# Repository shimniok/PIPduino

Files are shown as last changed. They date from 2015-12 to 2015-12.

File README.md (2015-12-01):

PIPduino
========

A 'duino clone you can Put In a Project. Small, breadboard-friendly 'duinos are compact and work
great on a breadboard. But you need a baseboard to embed them in a project.

PIPduino already has ports for I2C, SPI, Serial/FTDI, and servo-style connectors with VCC and GND
for each analog and digital pin.  It has a beefy regulator on board, too.

Buy one now on [Tindie](https://www.tindie.com/products/bot_thoughts/pipduino/).

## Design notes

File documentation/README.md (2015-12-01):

# PIPduino User Guide

PIPduino is a 'duino is easier and cheaper to permanently Put In a Project than the standard Arduino. [For sale on Tindie](https://www.tindie.com/products/bot_thoughts/pipduino).

## Overview

 * Use standalone boards from [Sparkfun](https://www.sparkfun.com/), [Pololu](http://www.pololu.com/), [Adafruit](https://www.adafruit.com/), etc.
 * ```I2C``` port with 4 connections for interfacing all those sensors
 * ```SPI/ISP``` port can be used for AVR In-System Programming or SPI port
 * All Digital and Analog pins exposed.
 * Servo-style ```signal```, ```VCC```, ```GND``` pins on *DIGITAL* and *ANALOG* ports
 * Select from a wide variety of power supply options
 * Programming and/or serial on ```FTDI``` port
 * ATmega328P at 16MHz, Arduino Optiboot, looks like an Uno board
 * Optional 3mm indicator LEDs (leave them off to reduce power consumption)
 * And more...

## Pinout
The PIPduino breaks out dedicated digital and analog pins as well as pins for Serial, SPI, and I2C. The tables below list all the Arduino Pins, and the PIPduino *Port* they are found on, and alternate functions.

### Digital

The primary function of the pins below is Arduino digital input and output.
Pins D10-D13 are also used for SPI (See *SPI/ISP* below).

| Arduino Pin | Alternate | Port |
|:---:|---|---|
| D0 | Serial RX (FTDI TXO) | FTDI |
| D1 | Serial TX (FTDI RXI) | FTDI |
| D2 | - | DIGITAL |
| D3 | PWM | DIGITAL |
| D4 | - | DIGITAL |
| D5 | PWM | DIGITAL |
| D6 | PWM | DIGITAL |
| D7 | - | DIGITAL |
| D8 | - | DIGITAL |
| D9 | PWM | DIGITAL |
| D10 | PWM | DIGITAL |
| D11 | PWM | SPI/ISP |
| D12 | - | SPI/ISP |
| D13 | LED | SPI/ISP |

### Analog

Arduino analog pins can also be used for digital input/output. Pins A4-A5 are
used for I2C (See *I2C* below). Pins A6-A7 are analog input, only.

| Arduino Pin | Alternate | Port |
|:---:|---|---|
| A0 | Digital | ANALOG |
| A1 | Digital | ANALOG |
| A2 | Digital | ANALOG |
| A3 | Digital | ANALOG |
| A4 | Digital, SDA | I2C |
| A5 | Digital, SCL | I2C |
| A6 | - | ANALOG |
| A7 | - | ANALOG |

### SPI/ISP
The SPI port doubles as the In-System Programming port (AVRISP). Use the SS
solder jumper under the board to select SPI:D10 to use the SPI port with D10
as the active-low Slave Select pin.

| Arduino Pin | Function | Port |
|:---:|---|---|
| D10 | SS | SPI/ISP |
| D11 | MOSI | SPI/ISP |
| D12 | MISO | SPI/ISP |
| D13 | SCK | SPI/ISP |

NOTE: there is a silkscreen error on R0.2: the SS solder jumper silkscreen
identifies the wrong digital pin for SPI operation. In fact, D10 is used for
Slave Select.

### I2C
The A4 and A5 pins are dedicated to I2C SDA and SCL use, respectively, since so
many sensors speak I2C. SMT pull-up resistors are installed on the board for
these pins. The board has connections for four I2C devices but you can also
daisy chain I2C devices, too.

| Arduino Pin | Function | Port |
|:---:|---|---|
| A4 | SDA | I2C |
| A5 | SCL | I2C |

### Serial / FTDI
The D0 and D1 pins are broken out to the FTDI/Serial port for TX (FTDI RXI) and RX (FTDI TXO) pins, respectively. The FTDI pins can be used for Arduino program downloading, or can be used for serial I/O. Because there's no pull-up they can also be used for GPIO pins D0 and D1.

| Arduino Pin | Function | FTDI | Port |
|:---:|---|:---:|---|
| D0 | Serial TX | RXI | FTDI |
| D1 | Serial RX | TXO | FTDI |

## Programming
### Arduino
PIPduino is Arduino compatible, so use the good ol' Arduino IDE.

### FTDI
Program with a standard FTDI cable or Sparkfun FTDI basic breakout or equivalent. Within the Arduino IDE, select the appropriate serial device, and choose "Arduino Uno" as the board.

### ISP
You can also program with ISP. On the bottom of the board, use the SS solder jumper to select ISP:RES for ISP programming.

## Power
Several options are available for powering your PIPduino and sensors/devices.

### Powering the Board
* Use the onboard regulator. Connect the VIN/GND port to a supply of anywhere from Vcc+0.23V to 16V.
* Bypass the regulator and supply 3.3V or 5V directly to any VCC/GND pin pair.
* FTDI can supply voltage through the VCC pin if the board is not powered. A diode allows you to plug in FTDI whether the board is already powered or not. It drops 0.2-0.5V depending on current draw.

CAUTION: in any case above, your FTDI adapter's output voltage must be LESS THAN the voltage on the VCC pins of the POWER, ANALOG, DIGITAL, and I2C ports.

### Powering Devices
A VCC and GND pin are provided for every port with a servo-style pinout (Signal, VCC, GND), plus there is a power distribution port, POWER, with 4 additional VCC/GND pairs. In most cases, the easiest option is to simply build a 0.1" pitch header/cable (or use a pre-built servo connector) to connect your device.

If your device requires a 3.3V supply, you can either use a separate regulator board to power 3.3V devices or use a 3.3V PIPduino.

### Onboard Regulator
The onboard regulator features reverse bias protection and thermal shutdown protection. Because of the DPAK package for the regulator IC and due to robust thermal design of the board, it has been tested to supply a full 500mA continuous without going into thermal shutdown.

In fact, I torture-tested the board, powering it with a 3S LiPo (~12V), dumping out over 520mA (above the rated spec for the regulator) for a good five minutes. The hottest spot I measured was a stable 140°C on the tab. Ambient temperature was 22°C. The regulator never went into thermal shutdown. When tested at approximately 250mA, the hottest temperature I found after several minutes was a stable 93°C.

Note that a lower input voltage won't make so much heat. And drawing less current means less heat. A higher ambient temperature will reduce heat dissipation, so keep that in mind.

CAUTION: when supplying maximum current, the board gets REALLY HOT!!

## Mounting

* Mounting holes for M3 (#4) size screws on a 40mm square
* Board size is 46mm (13/16") square

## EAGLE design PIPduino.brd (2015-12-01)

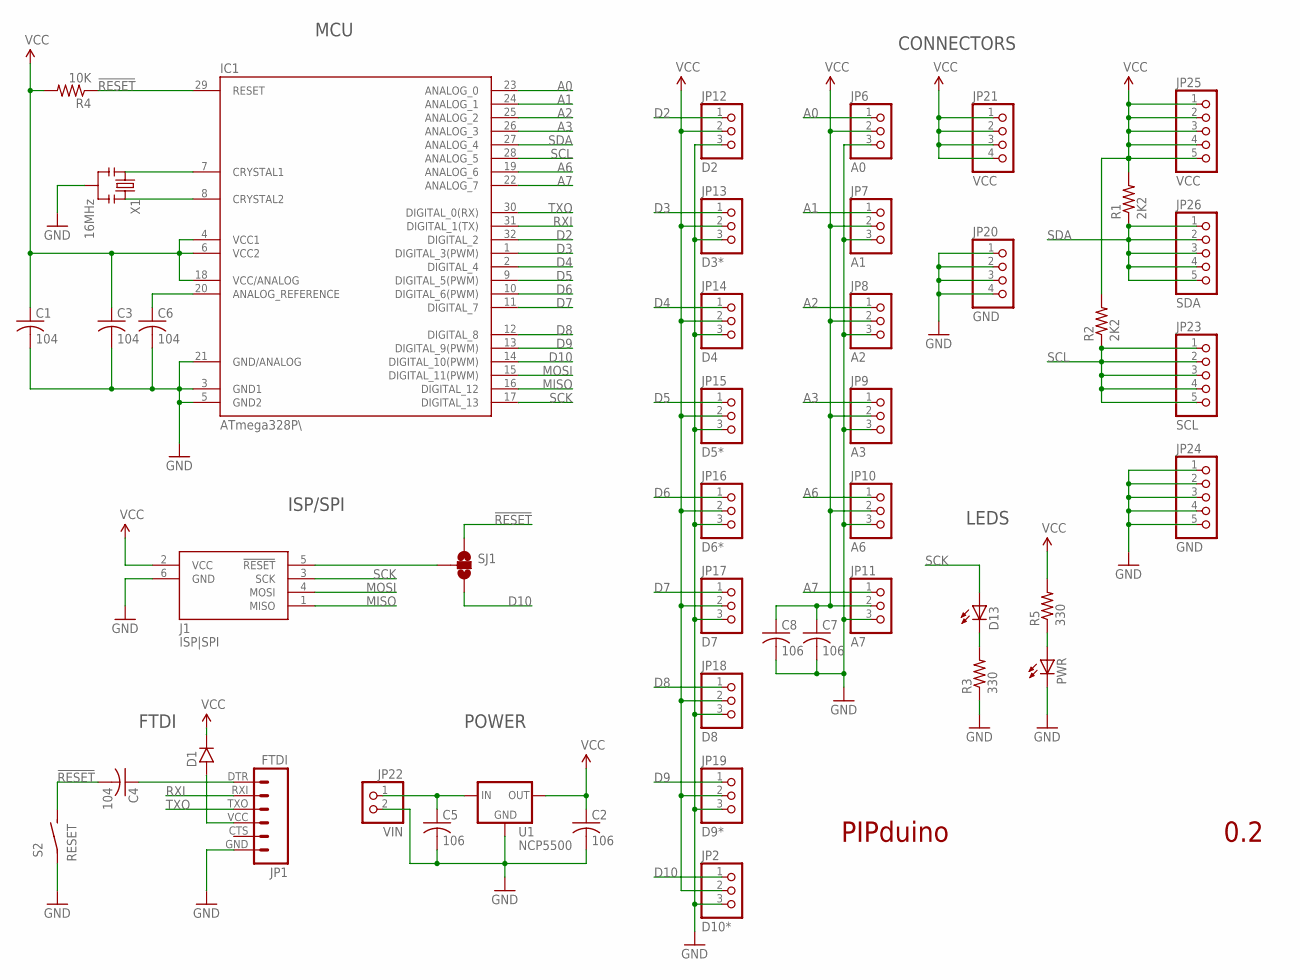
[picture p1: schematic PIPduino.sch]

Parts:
C1, C3, C4, C6: 104; C0603
C2, C5, C7, C8: 106; C1206
D1: DIODE_SOD123FL; SOD123FL
D13: LED3MM
IC1: ATmega328P\; TQFP32-08
J1: ISP|SPI; CON6P2R
JP1: FTDI; FTDI_BASIC
JP2: D10*; 1X03-S
JP6: A0; 1X03-S
JP7: A1; 1X03-S
JP8: A2; 1X03-S
JP9: A3; 1X03-S
JP10: A6; 1X03-S
JP11: A7; 1X03-S
JP12: D2; 1X03-S
JP13: D3*; 1X03-S
JP14: D4; 1X03-S
JP15: D5*; 1X03-S
JP16: D6*; 1X03-S
JP17: D7; 1X03-S
JP18: D8; 1X03-S
JP19: D9*; 1X03-S
JP20: GND; 1X04-S
JP21: VCC; 1X04-S
JP22: VIN; 1X02-S
JP23: SCL; 1X05-S
JP24: GND; 1X05-S
JP25: VCC; 1X05-S
JP26: SDA; 1X05-S
PWR: LED3MM
R1, R2: 2K2; R0603
R3, R5: 330; R0603
R4: 10K; R0603
S2: RESET; 3X4X2TACT
SJ1: SOLDERJUMPER_2WAYS; SJ_3
U1: NCP5500; DPAK
X1: 16MHz; CSTCE_V_C

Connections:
!RESET: C4.2, IC1.29 (RESET), R4.1, S2.P$2 (S), SJ1.1
A0: IC1.23 (ANALOG_0), JP6.1
A1: IC1.24 (ANALOG_1), JP7.1
A2: IC1.25 (ANALOG_2), JP8.1
A3: IC1.26 (ANALOG_3), JP9.1
A6: IC1.19 (ANALOG_6), JP10.1
A7: IC1.22 (ANALOG_7), JP11.1
D2: IC1.32 (DIGITAL_2), JP12.1
D3: IC1.1 (DIGITAL_3(PWM)), JP13.1
D4: IC1.2 (DIGITAL_4), JP14.1
D5: IC1.9 (DIGITAL_5(PWM)), JP15.1
D6: IC1.10 (DIGITAL_6(PWM)), JP16.1
D7: IC1.11 (DIGITAL_7), JP17.1
D8: IC1.12 (DIGITAL_8), JP18.1
D9: IC1.13 (DIGITAL_9(PWM)), JP19.1
D10: IC1.14 (DIGITAL_10(PWM)), JP2.1, SJ1.3
GND: C1.2, C2.2, C3.2, C5.2, C6.2, C7.2, C8.2, IC1.3 (GND1), IC1.5 (GND2), IC1.21 (GND/ANALOG), J1.6 (GND), JP1.GND (6), JP2.3, JP6.3, JP7.3, JP8.3, JP9.3, JP10.3, JP11.3, JP12.3, JP13.3, JP14.3, JP15.3, JP16.3, JP17.3, JP18.3, JP19.3, JP20.1, JP20.2, JP20.3, JP20.4, JP22.2, JP24.1, JP24.2, JP24.3, JP24.4, JP24.5, PWR.K (C), R3.1, S2.P$1, U1.4 (GND), X1.GND
MISO: IC1.16 (DIGITAL_12), J1.1 (MISO)
MOSI: IC1.15 (DIGITAL_11(PWM)), J1.4 (MOSI)
unnamed: D13.K (C), R3.2
unnamed: C5.1, JP22.1, U1.1 (VIN)
unnamed: J1.5 (!RESET), SJ1.2
unnamed: PWR.A, R5.1
unnamed: D1.A, JP1.VCC (4)
unnamed: C6.1, IC1.20 (ANALOG_REFERENCE)
unnamed: IC1.7 (CRYSTAL1), X1.X1
unnamed: IC1.8 (CRYSTAL2), X1.X2
unnamed: C4.1, JP1.DTR (1)
RXI: IC1.31 (DIGITAL_1(TX)), JP1.RXI (2)
SCK: D13.A, IC1.17 (DIGITAL_13), J1.3 (SCK)
SCL: IC1.28 (ANALOG_5), JP23.1, JP23.2, JP23.3, JP23.4, JP23.5, R2.1
SDA: IC1.27 (ANALOG_4), JP26.1, JP26.2, JP26.3, JP26.4, JP26.5, R1.1
TXO: IC1.30 (DIGITAL_0(RX)), JP1.TXO (3)
VCC: C1.1, C2.1, C3.1, C7.1, C8.1, D1.C, IC1.4 (VCC1), IC1.6 (VCC2), IC1.18 (VCC/ANALOG), J1.2 (VCC), JP2.2, JP6.2, JP7.2, JP8.2, JP9.2, JP10.2, JP11.2, JP12.2, JP13.2, JP14.2, JP15.2, JP16.2, JP17.2, JP18.2, JP19.2, JP21.1, JP21.2, JP21.3, JP21.4, JP25.1, JP25.2, JP25.3, JP25.4, JP25.5, R1.2, R2.2, R4.2, R5.2, U1.3 (VOUT)

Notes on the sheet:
FTDI
POWER
ISP/SPI
MCU
CONNECTORS
LEDS
PIPduino
0.2

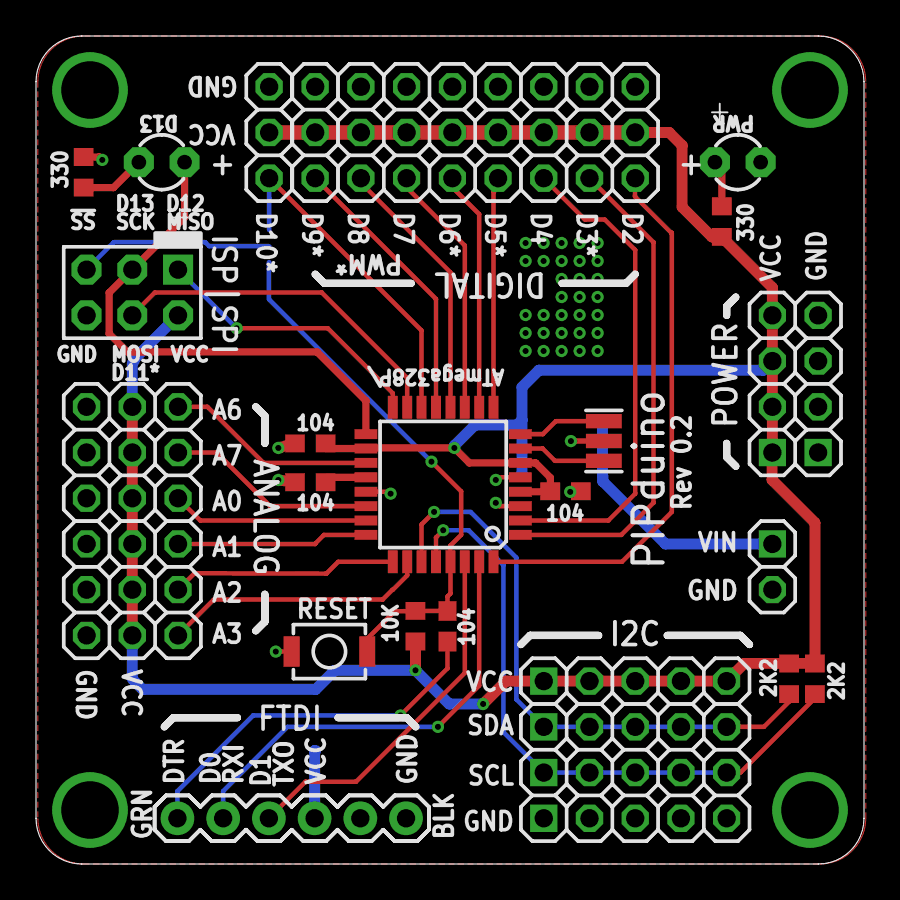
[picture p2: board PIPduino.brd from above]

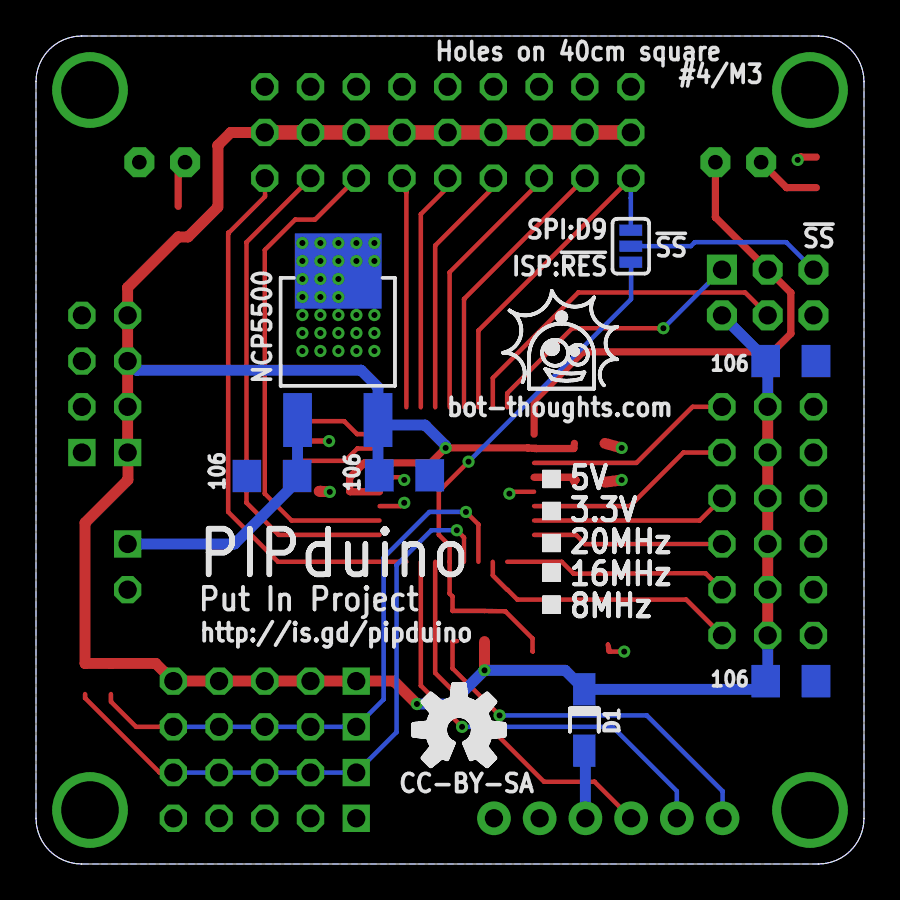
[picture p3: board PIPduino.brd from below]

Board: 2 copper layers, 46.0 x 46.0 mm, 45 parts (7 on the bottom side), 34 nets.

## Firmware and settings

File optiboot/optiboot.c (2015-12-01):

/**********************************************************/
/* Optiboot bootloader for Arduino                        */
/*                                                        */
/* http://optiboot.googlecode.com                         */
/*                                                        */
/* Arduino-maintained version : See README.TXT            */
/* http://code.google.com/p/arduino/                      */
/*                                                        */
/* Heavily optimised bootloader that is faster and        */
/* smaller than the Arduino standard bootloader           */
/*                                                        */
/* Enhancements:                                          */
/*   Fits in 512 bytes, saving 1.5K of code space         */
/*   Background page erasing speeds up programming        */
/*   Higher baud rate speeds up programming               */
/*   Written almost entirely in C                         */
/*   Customisable timeout with accurate timeconstant      */
/*   Optional virtual UART. No hardware UART required.    */
/*   Optional virtual boot partition for devices without. */
/*                                                        */
/* What you lose:                                         */
/*   Implements a skeleton STK500 protocol which is       */
/*     missing several features including EEPROM          */
/*     programming and non-page-aligned writes            */
/*   High baud rate breaks compatibility with standard    */
/*     Arduino flash settings                             */
/*                                                        */
/* Fully supported:                                       */
/*   ATmega168 based devices  (Diecimila etc)             */
/*   ATmega328P based devices (Duemilanove etc)           */
/*                                                        */
/* Alpha test                                             */
/*   ATmega1280 based devices (Arduino Mega)              */
/*                                                        */
/* Work in progress:                                      */
/*   ATmega644P based devices (Sanguino)                  */
/*   ATtiny84 based devices (Luminet)                     */
/*                                                        */
/* Does not support:                                      */
/*   USB based devices (eg. Teensy)                       */
/*                                                        */
/* Assumptions:                                           */
/*   The code makes several assumptions that reduce the   */
/*   code size. They are all true after a hardware reset, */
/*   but may not be true if the bootloader is called by   */
/*   other means or on other hardware.                    */
/*     No interrupts can occur                            */
/*     UART and Timer 1 are set to their reset state      */
/*     SP points to RAMEND                                */
/*                                                        */
/* Code builds on code, libraries and optimisations from: */
/*   stk500boot.c          by Jason P. Kyle               */
/*   Arduino bootloader    http://arduino.cc              */
/*   Spiff's 1K bootloader http://spiffie.org/know/arduino_1k_bootloader/bootloader.shtml */
/*   avr-libc project      http://nongnu.org/avr-libc     */
/*   Adaboot               http://www.ladyada.net/library/arduino/bootloader.html */
/*   AVR305                Atmel Application Note         */
/*                                                        */
/* This program is free software; you can redistribute it */
/* and/or modify it under the terms of the GNU General    */
/* Public License as published by the Free Software       */
/* Foundation; either version 2 of the License, or        */
/* (at your option) any later version.                    */
/*                                                        */
/* This program is distributed in the hope that it will   */
/* be useful, but WITHOUT ANY WARRANTY; without even the  */
/* implied warranty of MERCHANTABILITY or FITNESS FOR A   */
/* PARTICULAR PURPOSE.  See the GNU General Public        */
/* License for more details.                              */
/*                                                        */
/* You should have received a copy of the GNU General     */
/* Public License along with this program; if not, write  */
/* to the Free Software Foundation, Inc.,                 */
/* 59 Temple Place, Suite 330, Boston, MA  02111-1307 USA */
/*                                                        */
/* Licence can be viewed at                               */
/* http://www.fsf.org/licenses/gpl.txt                    */
/*                                                        */
/**********************************************************/


/**********************************************************/
/*                                                        */
/* Optional defines:                                      */
/*                                                        */
/**********************************************************/
/*                                                        */
/* BIG_BOOT:                                              */
/* Build a 1k bootloader, not 512 bytes. This turns on    */
/* extra functionality.                                   */
/*                                                        */
/* BAUD_RATE:                                             */
/* Set bootloader baud rate.                              */
/*                                                        */
/* LUDICROUS_SPEED:                                       */
/* 230400 baud :-)                                        */
/*                                                        */
/* SOFT_UART:                                             */
/* Use AVR305 soft-UART instead of hardware UART.         */
/*                                                        */
/* LED_START_FLASHES:                                     */
/* Number of LED flashes on bootup.                       */
/*                                                        */
/* LED_DATA_FLASH:                                        */
/* Flash LED when transferring data. For boards without   */
/* TX or RX LEDs, or for people who like blinky lights.   */
/*                                                        */
/* SUPPORT_EEPROM:                                        */
/* Support reading and writing from EEPROM. This is not   */
/* used by Arduino, so off by default.                    */
/*                                                        */
/* TIMEOUT_MS:                                            */
/* Bootloader timeout period, in milliseconds.            */
/* 500,1000,2000,4000,8000 supported.                     */
/*                                                        */
/**********************************************************/


/**********************************************************/
/* Version Numbers!                                       */
/*                                                        */
/* Arduino Optiboot now includes this Version number in   */
/* the source and object code.                            */
/*                                                        */
/* Version 3 was released as zip from the optiboot        */
/*  repository and was distributed with Arduino 0022.     */
/* Version 4 starts with the arduino repository commit    */
/*  that brought the arduino repository up-to-date with   */
/* the optiboot source tree changes since v3.             */
/*                                                        */
/**********************************************************/

/**********************************************************/
/* Edit History:					  */
/*							  */
/* 4.4 WestfW: add initialization of address to keep      */
/*             the compiler happy.  Change SC'ed targets. */
/*             Return the SW version via READ PARAM       */
/* 4.3 WestfW: catch framing errors in getch(), so that   */
/*             AVRISP works without HW kludges.           */
/*  http://code.google.com/p/arduino/issues/detail?id=368n*/
/* 4.2 WestfW: reduce code size, fix timeouts, change     */
/*             verifySpace to use WDT instead of appstart */
/* 4.1 WestfW: put version number in binary.		  */
/**********************************************************/

#define OPTIBOOT_MAJVER 4
#define OPTIBOOT_MINVER 4

#define MAKESTR(a) #a
#define MAKEVER(a, b) MAKESTR(a*256+b)

asm("  .section .version\n"
    "optiboot_version:  .word " MAKEVER(OPTIBOOT_MAJVER, OPTIBOOT_MINVER) "\n"
    "  .section .text\n");


#include <inttypes.h>
#include <avr/io.h>
#include <avr/pgmspace.h>

// <avr/boot.h> uses sts instructions, but this version uses out instructions
// This saves cycles and program memory.
#include "boot.h"


// We don't use <avr/wdt.h> as those routines have interrupt overhead we don't need.

#include "pin_defs.h"
#include "stk500.h"

#ifndef LED_START_FLASHES
#define LED_START_FLASHES 0
#endif

#ifdef LUDICROUS_SPEED
#define BAUD_RATE 230400L
#endif

/* set the UART baud rate defaults */
#ifndef BAUD_RATE
#if F_CPU >= 8000000L
#define BAUD_RATE   115200L // Highest rate Avrdude win32 will support
#elsif F_CPU >= 1000000L
#define BAUD_RATE   9600L   // 19200 also supported, but with significant error
#elsif F_CPU >= 128000L
#define BAUD_RATE   4800L   // Good for 128kHz internal RC
#else
#define BAUD_RATE 1200L     // Good even at 32768Hz
#endif
#endif

/* Switch in soft UART for hard baud rates */
#if (F_CPU/BAUD_RATE) > 280 // > 57600 for 16MHz
#ifndef SOFT_UART
#define SOFT_UART
#endif
#endif

/* Watchdog settings */
#define WATCHDOG_OFF    (0)
#define WATCHDOG_16MS   (_BV(WDE))
#define WATCHDOG_32MS   (_BV(WDP0) | _BV(WDE))
#define WATCHDOG_64MS   (_BV(WDP1) | _BV(WDE))
#define WATCHDOG_125MS  (_BV(WDP1) | _BV(WDP0) | _BV(WDE))
#define WATCHDOG_250MS  (_BV(WDP2) | _BV(WDE))
#define WATCHDOG_500MS  (_BV(WDP2) | _BV(WDP0) | _BV(WDE))
#define WATCHDOG_1S     (_BV(WDP2) | _BV(WDP1) | _BV(WDE))
#define WATCHDOG_2S     (_BV(WDP2) | _BV(WDP1) | _BV(WDP0) | _BV(WDE))
#ifndef __AVR_ATmega8__
#define WATCHDOG_4S     (_BV(WDP3) | _BV(WDE))
#define WATCHDOG_8S     (_BV(WDP3) | _BV(WDP0) | _BV(WDE))
#endif

/* Function Prototypes */
/* The main function is in init9, which removes the interrupt vector table */
/* we don't need. It is also 'naked', which means the compiler does not    */
/* generate any entry or exit code itself. */
int main(void) __attribute__ ((naked)) __attribute__ ((section (".init9")));
void putch(char);
uint8_t getch(void);
static inline void getNch(uint8_t); /* "static inline" is a compiler hint to reduce code size */
void verifySpace();
static inline void flash_led(uint8_t);
uint8_t getLen();
static inline void watchdogReset();
void watchdogConfig(uint8_t x);
#ifdef SOFT_UART
void uartDelay() __attribute__ ((naked));
#endif
void appStart() __attribute__ ((naked));

#if defined(__AVR_ATmega168__)
#define RAMSTART (0x100)
#define NRWWSTART (0x3800)
#elif defined(__AVR_ATmega328P__)
#define RAMSTART (0x100)
#define NRWWSTART (0x7000)
#elif defined (__AVR_ATmega644P__)
#define RAMSTART (0x100)
#define NRWWSTART (0xE000)
#elif defined(__AVR_ATtiny84__)
#define RAMSTART (0x100)
#define NRWWSTART (0x0000)
#elif defined(__AVR_ATmega1280__)
#define RAMSTART (0x200)
#define NRWWSTART (0xE000)
#elif defined(__AVR_ATmega8__) || defined(__AVR_ATmega88__)
#define RAMSTART (0x100)
#define NRWWSTART (0x1800)
#endif

/* C zero initialises all global variables. However, that requires */
/* These definitions are NOT zero initialised, but that doesn't matter */
/* This allows us to drop the zero init code, saving us memory */
#define buff    ((uint8_t*)(RAMSTART))
#ifdef VIRTUAL_BOOT_PARTITION
#define rstVect (*(uint16_t*)(RAMSTART+SPM_PAGESIZE*2+4))
#define wdtVect (*(uint16_t*)(RAMSTART+SPM_PAGESIZE*2+6))
#endif

/* main program starts here */
int main(void) {
  uint8_t ch;

  /*
   * Making these local and in registers prevents the need for initializing
   * them, and also saves space because code no longer stores to memory.
   * (initializing address keeps the compiler happy, but isn't really
   *  necessary, and uses 4 bytes of flash.)
   */
  register uint16_t address = 0;
  register uint8_t  length;

  // After the zero init loop, this is the first code to run.
  //
  // This code makes the following assumptions:
  //  No interrupts will execute
  //  SP points to RAMEND
  //  r1 contains zero
  //
  // If not, uncomment the following instructions:
  // cli();
  asm volatile ("clr __zero_reg__");
#ifdef __AVR_ATmega8__
  SP=RAMEND;  // This is done by hardware reset
#endif

  // Adaboot no-wait mod
  ch = MCUSR;
  MCUSR = 0;
  if (!(ch & _BV(EXTRF))) appStart();

#if LED_START_FLASHES > 0
  // Set up Timer 1 for timeout counter
  TCCR1B = _BV(CS12) | _BV(CS10); // div 1024
#endif
#ifndef SOFT_UART
#ifdef __AVR_ATmega8__
  UCSRA = _BV(U2X); //Double speed mode USART
  UCSRB = _BV(RXEN) | _BV(TXEN);  // enable Rx & Tx
  UCSRC = _BV(URSEL) | _BV(UCSZ1) | _BV(UCSZ0);  // config USART; 8N1
  UBRRL = (uint8_t)( (F_CPU + BAUD_RATE * 4L) / (BAUD_RATE * 8L) - 1 );
#else
  UCSR0A = _BV(U2X0); //Double speed mode USART0
  UCSR0B = _BV(RXEN0) | _BV(TXEN0);
  UCSR0C = _BV(UCSZ00) | _BV(UCSZ01);
  UBRR0L = (uint8_t)( (F_CPU + BAUD_RATE * 4L) / (BAUD_RATE * 8L) - 1 );
#endif
#endif

  // Set up watchdog to trigger after 500ms
  watchdogConfig(WATCHDOG_1S);

  /* Set LED pin as output */
  LED_DDR |= _BV(LED);

#ifdef SOFT_UART
  /* Set TX pin as output */
  UART_DDR |= _BV(UART_TX_BIT);
#endif

#if LED_START_FLASHES > 0
  /* Flash onboard LED to signal entering of bootloader */
  flash_led(LED_START_FLASHES * 2);
#endif

  /* Forever loop */
  for (;;) {
    /* get character from UART */
    ch = getch();

    if(ch == STK_GET_PARAMETER) {
      unsigned char which = getch();
      verifySpace();
      if (which == 0x82) {
	/*
	 * Send optiboot version as "minor SW version"
	 */
	putch(OPTIBOOT_MINVER);
      } else if (which == 0x81) {
	  putch(OPTIBOOT_MAJVER);
      } else {
	/*
	 * GET PARAMETER returns a generic 0x03 reply for
         * other parameters - enough to keep Avrdude happy
	 */
	putch(0x03);
      }
    }
    else if(ch == STK_SET_DEVICE) {
      // SET DEVICE is ignored
      getNch(20);
    }
    else if(ch == STK_SET_DEVICE_EXT) {
      // SET DEVICE EXT is ignored
      getNch(5);
    }
    else if(ch == STK_LOAD_ADDRESS) {
      // LOAD ADDRESS
      uint16_t newAddress;
      newAddress = getch();
      newAddress = (newAddress & 0xff) | (getch() << 8);
#ifdef RAMPZ
      // Transfer top bit to RAMPZ
      RAMPZ = (newAddress & 0x8000) ? 1 : 0;
#endif
      newAddress += newAddress; // Convert from word address to byte address
      address = newAddress;
      verifySpace();
    }
    else if(ch == STK_UNIVERSAL) {
      // UNIVERSAL command is ignored
      getNch(4);
      putch(0x00);
    }
    /* Write memory, length is big endian and is in bytes */
    else if(ch == STK_PROG_PAGE) {
      // PROGRAM PAGE - we support flash programming only, not EEPROM
      uint8_t *bufPtr;
      uint16_t addrPtr;

      getch();			/* getlen() */
      length = getch();
      getch();

      // If we are in RWW section, immediately start page erase
      if (address < NRWWSTART) __boot_page_erase_short((uint16_t)(void*)address);

      // While that is going on, read in page contents
      bufPtr = buff;
      do *bufPtr++ = getch();
      while (--length);

      // If we are in NRWW section, page erase has to be delayed until now.
      // Todo: Take RAMPZ into account
      if (address >= NRWWSTART) __boot_page_erase_short((uint16_t)(void*)address);

      // Read command terminator, start reply
      verifySpace();

      // If only a partial page is to be programmed, the erase might not be complete.
      // So check that here
      boot_spm_busy_wait();

#ifdef VIRTUAL_BOOT_PARTITION
      if ((uint16_t)(void*)address == 0) {
        // This is the reset vector page. We need to live-patch the code so the
        // bootloader runs.
        //
        // Move RESET vector to WDT vector
        uint16_t vect = buff[0] | (buff[1]<<8);
        rstVect = vect;
        wdtVect = buff[8] | (buff[9]<<8);
        vect -= 4; // Instruction is a relative jump (rjmp), so recalculate.
        buff[8] = vect & 0xff;
        buff[9] = vect >> 8;

        // Add jump to bootloader at RESET vector
        buff[0] = 0x7f;
        buff[1] = 0xce; // rjmp 0x1d00 instruction
      }
#endif

      // Copy buffer into programming buffer
      bufPtr = buff;
      addrPtr = (uint16_t)(void*)address;
      ch = SPM_PAGESIZE / 2;
      do {
        uint16_t a;
        a = *bufPtr++;
        a |= (*bufPtr++) << 8;
        __boot_page_fill_short((uint16_t)(void*)addrPtr,a);
        addrPtr += 2;
      } while (--ch);

      // Write from programming buffer
      __boot_page_write_short((uint16_t)(void*)address);
      boot_spm_busy_wait();

#if defined(RWWSRE)
      // Reenable read access to flash
      boot_rww_enable();
#endif

    }
    /* Read memory block mode, length is big endian.  */
    else if(ch == STK_READ_PAGE) {
      // READ PAGE - we only read flash
      getch();			/* getlen() */
      length = getch();
      getch();

      verifySpace();
#ifdef VIRTUAL_BOOT_PARTITION
      do {
        // Undo vector patch in bottom page so verify passes
        if (address == 0)       ch=rstVect & 0xff;
        else if (address == 1)  ch=rstVect >> 8;
        else if (address == 8)  ch=wdtVect & 0xff;
        else if (address == 9) ch=wdtVect >> 8;
        else ch = pgm_read_byte_near(address);
        address++;
        putch(ch);
      } while (--length);
#else
#ifdef __AVR_ATmega1280__
//      do putch(pgm_read_byte_near(address++));
//      while (--length);
      do {
        uint8_t result;
        __asm__ ("elpm %0,Z\n":"=r"(result):"z"(address));
        putch(result);
        address++;
      }
      while (--length);
#else
      do putch(pgm_read_byte_near(address++));
      while (--length);
#endif
#endif
    }

    /* Get device signature bytes  */
    else if(ch == STK_READ_SIGN) {
      // READ SIGN - return what Avrdude wants to hear
      verifySpace();
      putch(SIGNATURE_0);
      putch(SIGNATURE_1);
      putch(SIGNATURE_2);
    }
    else if (ch == 'Q') {
      // Adaboot no-wait mod
      watchdogConfig(WATCHDOG_16MS);
      verifySpace();
    }
    else {
      // This covers the response to commands like STK_ENTER_PROGMODE
      verifySpace();
    }
    putch(STK_OK);
  }
}

void putch(char ch) {
#ifndef SOFT_UART
  while (!(UCSR0A & _BV(UDRE0)));
  UDR0 = ch;
#else
  __asm__ __volatile__ (
    "   com %[ch]\n" // ones complement, carry set
    "   sec\n"
    "1: brcc 2f\n"
    "   cbi %[uartPort],%[uartBit]\n"
    "   rjmp 3f\n"
    "2: sbi %[uartPort],%[uartBit]\n"
    "   nop\n"
    "3: rcall uartDelay\n"
    "   rcall uartDelay\n"
    "   lsr %[ch]\n"
    "   dec %[bitcnt]\n"
    "   brne 1b\n"
    :
    :
      [bitcnt] "d" (10),
      [ch] "r" (ch),
      [uartPort] "I" (_SFR_IO_ADDR(UART_PORT)),
      [uartBit] "I" (UART_TX_BIT)
    :
      "r25"
  );
#endif
}

uint8_t getch(void) {
  uint8_t ch;

#ifdef LED_DATA_FLASH
#ifdef __AVR_ATmega8__
  LED_PORT ^= _BV(LED);
#else
  LED_PIN |= _BV(LED);
#endif
#endif

#ifdef SOFT_UART
  __asm__ __volatile__ (
    "1: sbic  %[uartPin],%[uartBit]\n"  // Wait for start edge
    "   rjmp  1b\n"
    "   rcall uartDelay\n"          // Get to middle of start bit
    "2: rcall uartDelay\n"              // Wait 1 bit period
    "   rcall uartDelay\n"              // Wait 1 bit period
    "   clc\n"
    "   sbic  %[uartPin],%[uartBit]\n"
    "   sec\n"
    "   dec   %[bitCnt]\n"
    "   breq  3f\n"
    "   ror   %[ch]\n"
    "   rjmp  2b\n"
    "3:\n"
    :
      [ch] "=r" (ch)
    :
      [bitCnt] "d" (9),
      [uartPin] "I" (_SFR_IO_ADDR(UART_PIN)),
      [uartBit] "I" (UART_RX_BIT)
    :
      "r25"
);
#else
  while(!(UCSR0A & _BV(RXC0)))
    ;
  if (!(UCSR0A & _BV(FE0))) {
      /*
       * A Framing Error indicates (probably) that something is talking
       * to us at the wrong bit rate.  Assume that this is because it
       * expects to be talking to the application, and DON'T reset the
       * watchdog.  This should cause the bootloader to abort and run
       * the application "soon", if it keeps happening.  (Note that we
       * don't care that an invalid char is returned...)
       */
    watchdogReset();
  }
  
  ch = UDR0;
#endif

#ifdef LED_DATA_FLASH
#ifdef __AVR_ATmega8__
  LED_PORT ^= _BV(LED);
#else
  LED_PIN |= _BV(LED);
#endif
#endif

  return ch;
}

#ifdef SOFT_UART
// AVR350 equation: #define UART_B_VALUE (((F_CPU/BAUD_RATE)-23)/6)
// Adding 3 to numerator simulates nearest rounding for more accurate baud rates
#define UART_B_VALUE (((F_CPU/BAUD_RATE)-20)/6)
#if UART_B_VALUE > 255
#error Baud rate too slow for soft UART
#endif

void uartDelay() {
  __asm__ __volatile__ (
    "ldi r25,%[count]\n"
    "1:dec r25\n"
    "brne 1b\n"
    "ret\n"
    ::[count] "M" (UART_B_VALUE)
  );
}
#endif

void getNch(uint8_t count) {
  do getch(); while (--count);
  verifySpace();
}

void verifySpace() {
  if (getch() != CRC_EOP) {
    watchdogConfig(WATCHDOG_16MS);    // shorten WD timeout
    while (1)			      // and busy-loop so that WD causes
      ;				      //  a reset and app start.
  }
  putch(STK_INSYNC);
}

#if LED_START_FLASHES > 0
void flash_led(uint8_t count) {
  do {
    TCNT1 = -(F_CPU/(1024*16));
    TIFR1 = _BV(TOV1);
    while(!(TIFR1 & _BV(TOV1)));
#ifdef __AVR_ATmega8__
    LED_PORT ^= _BV(LED);
#else
    LED_PIN |= _BV(LED);
#endif
    watchdogReset();
  } while (--count);
}
#endif
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

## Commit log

2014-08-15 R0.1 as ordered
    [PIPduino.brd, PIPduino.sch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]
2014-08-15 Added 5th I2C, fixed silk for VIN
    [PIPduino.brd, PIPduino.sch]
2014-08-26 Revised power pin silk to be more visible; moved rev silk to make room.
    [PIPduino.brd]
2014-08-26 Fixed silk text "spin" setting
    [PIPduino.brd]
2014-08-26 Surrounded top screw holes with GND
    [PIPduino.brd, PIPduino.sch]
2014-08-26 Removed top 5V polygon, star pattern power, 106's on analog, 104 on aref, larger power traces, removed polygons on top mounting holes
    [PIPduino.brd, PIPduino.sch]
2014-08-26 added bootloader. Minor board tweaks
2014-09-02 Final LDO regulator selection, rearrangement, silk updates, fixed missing D10
    [PIPduino.brd, PIPduino.sch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]
2014-09-02 Fixed missing checkboxes in silk
    [PIPduino.brd]
2014-09-02 Fixed some silk errors
    [PIPduino.brd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]

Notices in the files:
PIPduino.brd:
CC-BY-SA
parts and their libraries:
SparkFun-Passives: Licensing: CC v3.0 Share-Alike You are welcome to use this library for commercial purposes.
